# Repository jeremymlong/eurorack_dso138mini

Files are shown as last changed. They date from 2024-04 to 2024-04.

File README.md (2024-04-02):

# Eurorack DSO138 mini
Simple panel and buttons for eurorack adaptation of a DSO138 mini oscilloscope. I didn't try to adapt the switches, instead I just did a simple cut out in the panel to access the switches that came with it.

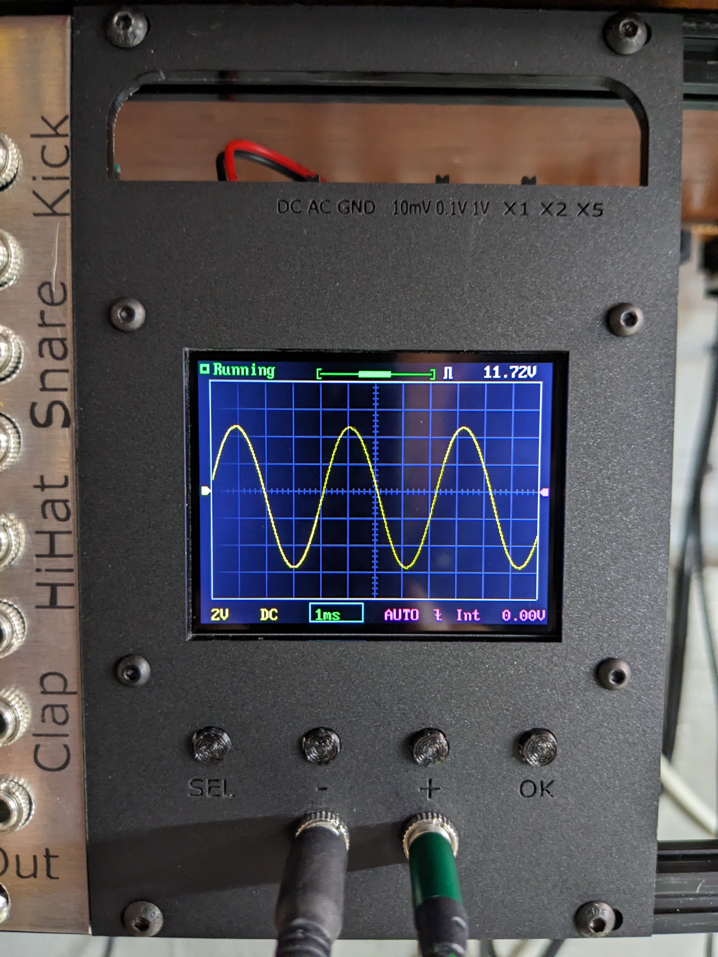
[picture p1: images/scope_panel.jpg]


## Specs
* 16HP

## BOM
| Description | Quantity | Link |
|-----|-----|-----|
| DSO138 mini kit | 1 | [Aliexpress](https://www.aliexpress.us/item/2251832872065620.html) (This is the one I bought, but there may be cheaper ones. I paid about 17USD for mine.) |
| Panel | 1 | [Laser cut acrylic](panel.svg) or 3D printed |
| Button caps | 4 | [3D printed](button_cap.stl) |
| Jacks (These form a passive multiple. I used two for my build) | 1 to 4 | [Tayda](https://www.taydaelectronics.com/3-5mm-earphone-mono-plug.html) |
| Standoffs | 4 | [Laser cut acrylic](panel.svg) or 3D printed |
| M2.5 x 20mm button head screws | 4 |  |
| M2.5 nuts | 4 |  |
| Power connector | 1 | [Tayda](https://www.taydaelectronics.com/dc-power-jack-2-1mm-round-type-panel-mount-1.html) or 16 pin eurorack header |

## Build notes
1. Assemble the kit with the following changes:
    * I left the LED off, it's a power LED and you can't see it anyway. It could be hooked up as a trigger LED from PA15.
    * Install right angled pin header instead of BNC connector.
    * I didn't install the second right angle battery pin header. Instead I saved this for a +5V connector.
    * I didn't bother with the power switch since I knew I would just have it turn on with the rest of my setup. Plus it won't be accessible once mounted in a rack.
1. Cut out the panel, or 3D print it. I used 3mm laser cut acrylic for mine. The file [panel.svg](panel.svg) is what I used for laser cutting. I expect the panel could be extruded for 3D printing too.
    * My panel was a little thick for my jacks so I milled the inside of the panel down a bit.
    * Inside the waste of the button cutouts of the panel are standoffs. These standoffs are for the screen to space it from the panel.
1. 3D print the button caps. [button_cap.stl](button_cap.stl) These caps should fit over the 6mm tall buttons which come with the kit.
1. Install the jacks in the panel wired as a passive multiple.
1. Use the longer cable to connect the probe pin header to the installed jacks. Red to tips, black to grounds.
    * You can also reference this [PDF](DSO138mini_PowerSupplyOptions.pdf) for more information about powering the scope.
1. There's a nice prototyping section on the analog board. I used this to install the second pin header. Then wired to the SW4's inner center leg (the one with the trace). I connected the ground to the unused charger board ground hole.
    * These's plenty of space on this prototyping area. If you want, you could connect a 16 pin eurorack header.
1. Use the shorter cable to connect to a power jack.

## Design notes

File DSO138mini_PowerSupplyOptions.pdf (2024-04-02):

DN138-22v01

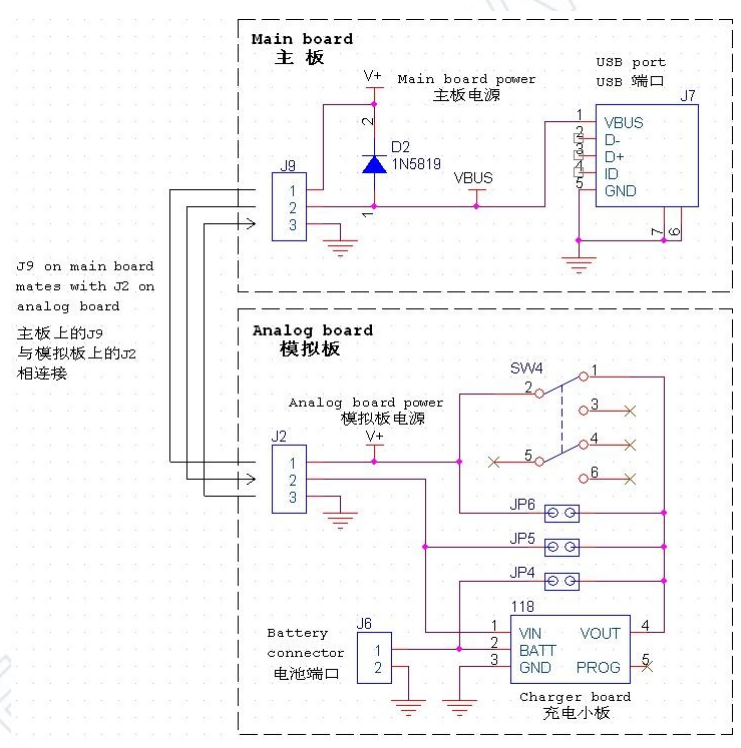
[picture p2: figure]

JYE Tech | - 1 - | www.jyetech.com

# DSO138mini Power Supply Options

Applicable analog board versions: 109-13801-00H and 109-13801-00J

DSO138mini has the following power supply options:
1) USB
2) 3.7V Li-ion battery
3) Any DC power supply with voltage 3.5V – 6V

The figure below shows the schematic of DSO138mini power supply.

It can be seen that there are two power input ports for DSO138mini. One is USB (J7 on the main board). The other is J6 on the analog board (for battery). The box 118 is battery charger board. SW4 is power switch.

When USB power is applied it powers the main board via diode D2. It also powers the analog board through J9 (on main board) pin1 to J2 (on analog board) pin1 if analog board and main board are connected. The same USB power will also charge battery through the path J9 pin2 – J2 pin2 – 118 board. The power switch SW4 does not function in this case.

When USB power is not used but battery is connected battery will power the main board and analog board through 118 and SW4. SW4 can be used to cut off power in this case.

The table below summarized the configurations for various power supply options.

Power Supply | Input Connector | Need Battery Charger? | Charger Board 118 | JP4 | Remarks
USB | USB 口 (J7 on Main board) | No | Not install | open
| | Yes | Install | open
3.7V Li-ion Battery | J6 on analog board | No | Not install | closed | Do not apply USB power simultaneously
| | Yes | Install | open
3.5V – 6V DC | J6 on analog board | No | Not install | closed | Do not apply USB power simultaneously

DN138-22v01

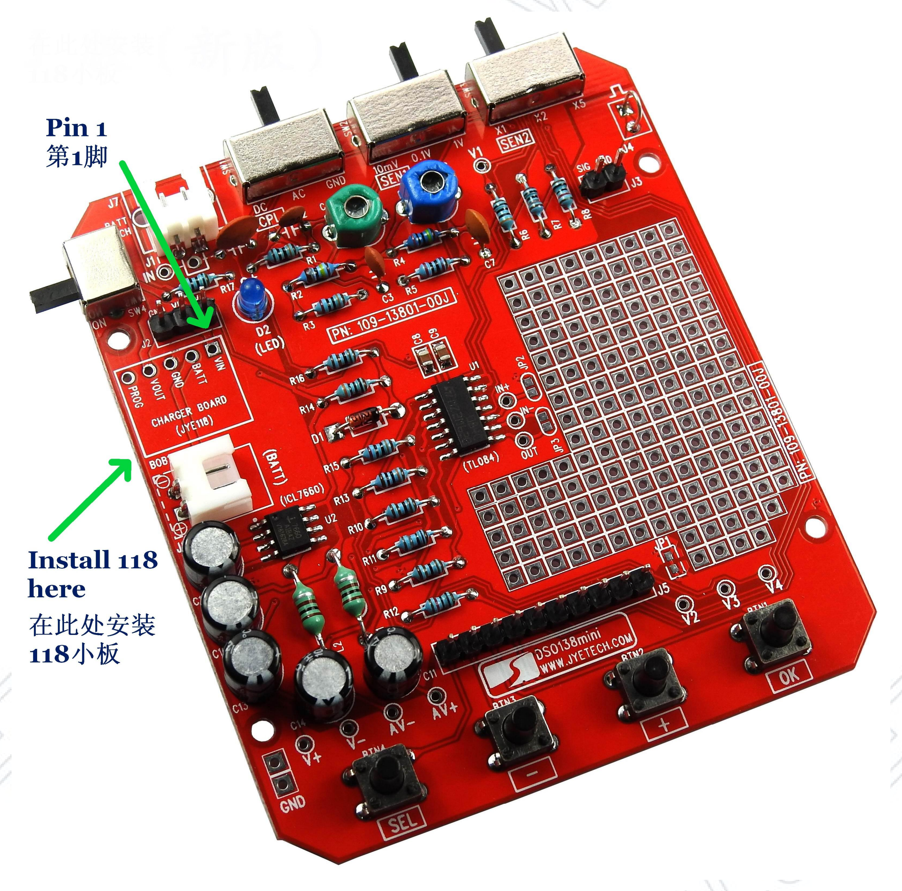
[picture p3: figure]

JYE Tech | - 2 - | www.jyetech.com

In general
1) If you want to use USB only just connect power supply through J7 on the main board. Keep JP4 open no matter battery charger board 118 is installed or not.
2) If you want to use 3.7V Li-ion battery only and don’t need the charger, connect battery through J6 on the analog board and keep JP4 closed. Do not apply USB power in this case.
3) If you want to use USB or Li-ion battery and want battery be charged by USB, make sure charger board 118 is installed. Keep JP4 open.
4) If you want to use a different power supply (voltage between 3.5V – 6V) connect the power source to J6 on the analog board. Do not install charger board 118 and keep JP4 closed. Make sure USB power is not applied.

About JP5
JP5 is for compatibility to earlier H version main board. When the analog board is to use with H version main board JP5 should be closed. Otherwise, keep it open.

About JP6
JP6 is a bypass of power switch SW4. Keep this JP6 closed if SW4 is not used.

About power switch SW4
SW4 is for disconnecting power when battery is used. It won’t disconnect USB power because diode D2 on the main board. If you want SW4 to disconnect USB power you can remove D2. Please note that after D2 is removed the main board won’t get power without analog board connected even USB power has been applied.

LCD can’t be turned off at charging?
The LCD will stay ON at battery charging for the same reason stated above. If you want LCD be turned off when battery is being charged you can remove the diode D2 on the main board. Then you will be able turn of LCD by SW4.

Installation of battery charger board 118
The following picture shows the position and orientation for installation of battery charger board 118.

DN138-22v01

JYE Tech | - 3 - | www.jyetech.com

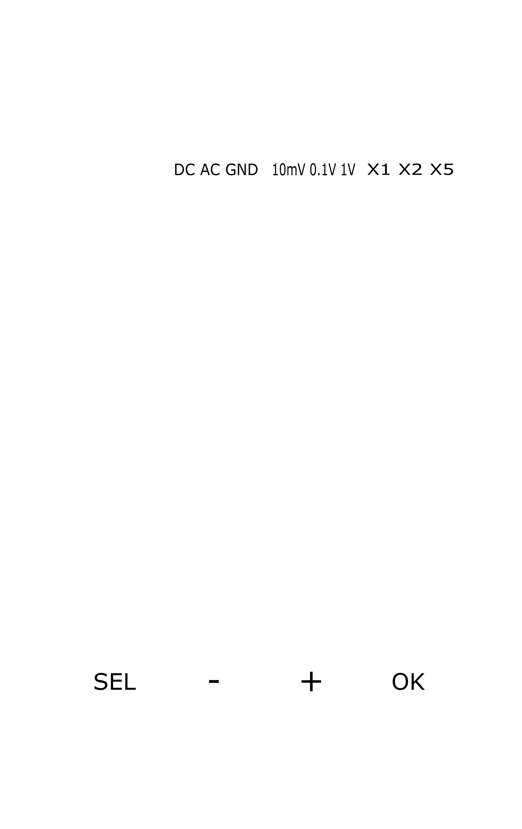
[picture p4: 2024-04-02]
panel_labels.png

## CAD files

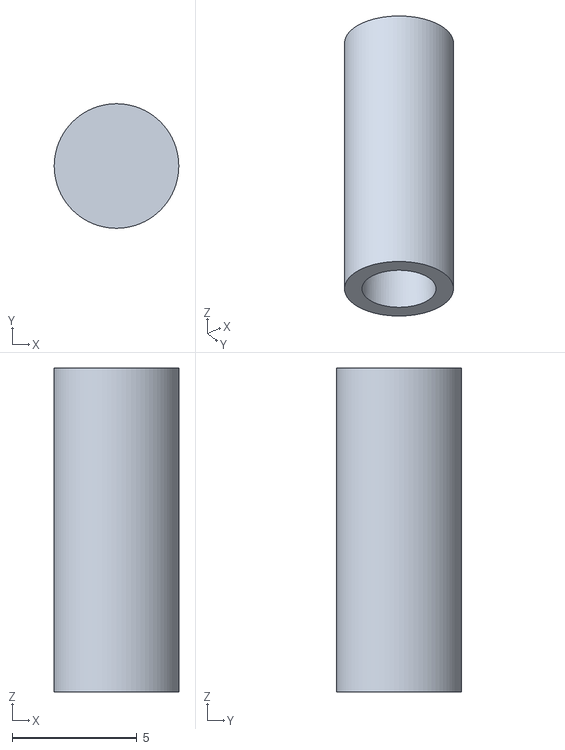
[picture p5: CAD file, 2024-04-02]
button_cap.stl
5.00 x 5.00 x 13.0

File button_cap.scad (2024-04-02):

$fn = 80;
button_outer_diameter = 5;
button_outer_height = 13;

button_inner_height = 6;
button_inner_top_diameter = 3;
button_inner_base_diameter = 3.4;

difference() {
    cylinder(button_outer_height, d1 = button_outer_diameter, d2 = button_outer_diameter);
    cylinder(button_inner_height, d1 = button_inner_base_diameter, d2 = button_inner_top_diameter);
}
